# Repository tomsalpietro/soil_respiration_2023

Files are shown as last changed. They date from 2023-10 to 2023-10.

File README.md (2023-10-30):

# Soil Respiration Project
Repository of the soil respiration project

# Building
To build the image, run the following commands:
```
west build
west sign -t imgtool
```
# Flashing
To flash, run:
```
west flash
```
# OTA
To update the firmware over-the-air, run the following commands in the ./build/zephyr directory:
```
sudo python3 -m http.server 80
```

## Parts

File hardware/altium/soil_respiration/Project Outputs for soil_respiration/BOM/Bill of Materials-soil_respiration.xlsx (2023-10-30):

Description | Designator | Footprint | LibRef | Quantity | Category | Supplier 1 | Supplier Currency 1 | Supplier Order Qty 1 | Supplier Packaging 1 | Supplier Part Number 1 | Supplier Stock 1 | Supplier Subtotal 1 | Supplier Subtotal per Board 1 | Supplier Unit Price 1
CONN HEADER VERT 2POS 2.54MM | J1 | HDR2x1 | CMP-1502-00584-2 | 1 |  | Digi-Key | AUD | 1 | Bulk | 732-2695-ND | 10842 | 0.83897 | 0.83897 | 0.83897
LQ Relays, 5 V Coil Voltage, 400 mW Nominal Operating Power, -40 to 85 degC, 5-Pin LQ, Carton, Case, RoHS | K1, K2 | ALQ105 | CMP-1503-00191-1 | 2 |  | Digi-Key | AUD | 2 | Tube | 255-3565-ND | 80829 | 3.93 | 3.93 | 1.96
ON Semi TIP120G NPN Darlington Transistor 8 A 60 V HFE: 1000 3-Pin TO-220 | Q1, Q2 | TIP120G | TIP120G | 2 | BJTs | Digi-Key | AUD | 2 | Tube | TIP120GOS-ND | 0 | 2.19 | 2.19 | 1.09
Res 1K Ohm 1% 2W 1206 | R1, R2 | 1206-1k | 3503G2B1K0FTDF | 2 | Chip SMD Resistors | Digi-Key | USD |  |  | 1712-3503G2B1K0FTDFTR-ND | 0
ESP32-WROOM-32E 4MB Flash | U2 | ESP32 | ESP32-DEVKITC-32E | 1 | RF Semiconductors and Devices | Digi-Key | AUD | 1 | Bulk | 1965-ESP32-DEVKITC-32E-ND | 580 | 15.58 | 15.58 | 15.58
SCD30 Series 5.5 V 75 mA ±3% Carbon Dioxide (CO2) Sensor Module | U1 | SCD30 | SCD30 | 1 | Sensors | Digi-Key | AUD | 1 | Tray | 1649-1098-ND | 21436 | 92.57 | 92.57 | 92.57
Diode Gen Purp 50V 1A Sma | D1, D2 | S1A | S1A | 2 | Uncategorized | Digi-Key | AUD | 2 |  | 1655-S1ADKR-ND | 79124 | 0.38952 | 0.38952 | 0.19476

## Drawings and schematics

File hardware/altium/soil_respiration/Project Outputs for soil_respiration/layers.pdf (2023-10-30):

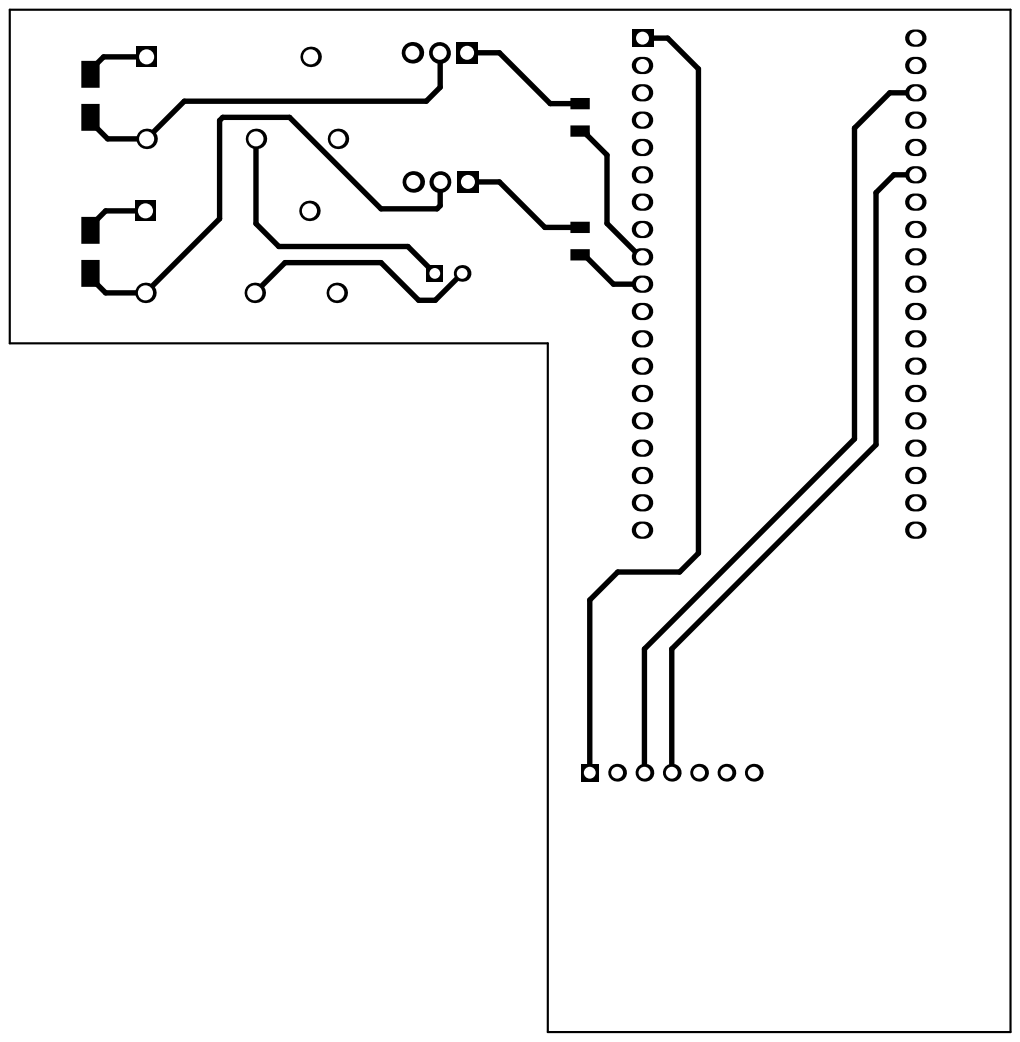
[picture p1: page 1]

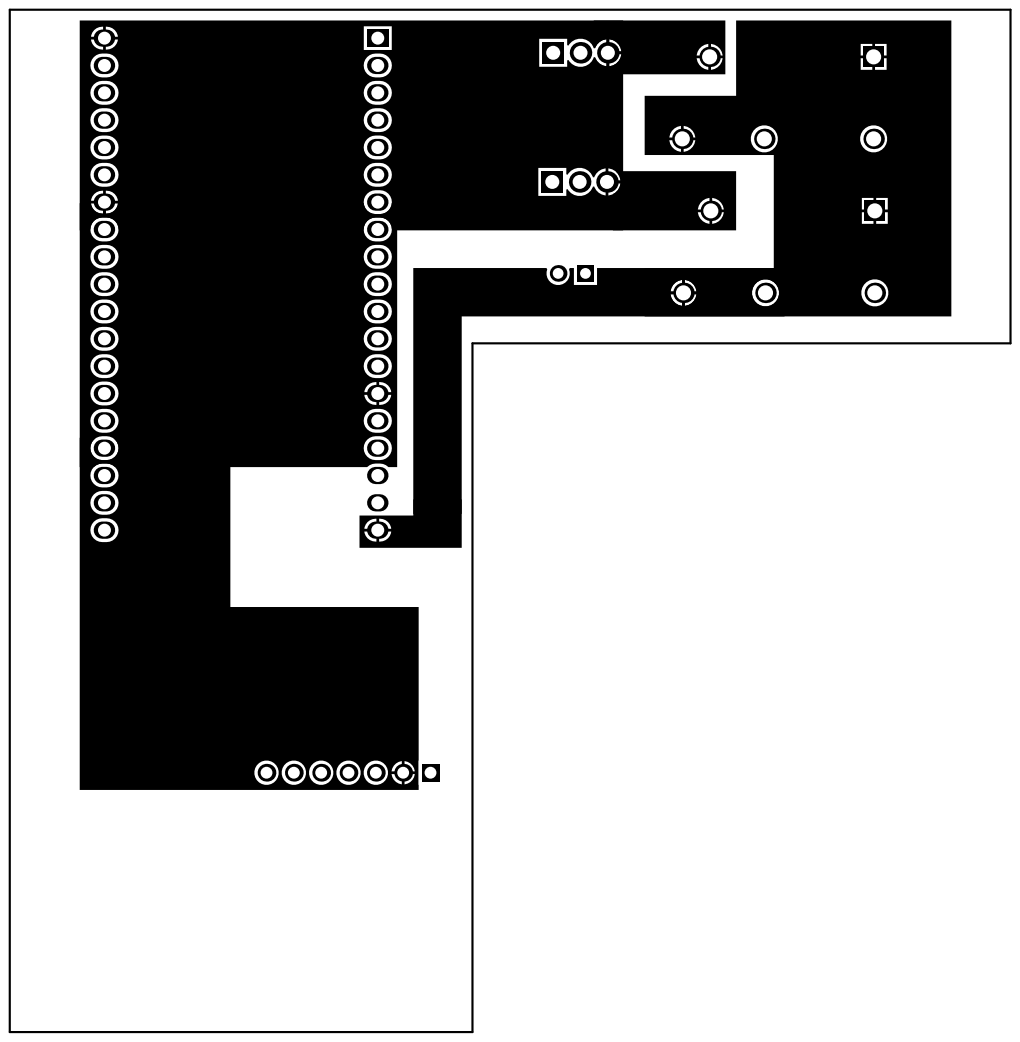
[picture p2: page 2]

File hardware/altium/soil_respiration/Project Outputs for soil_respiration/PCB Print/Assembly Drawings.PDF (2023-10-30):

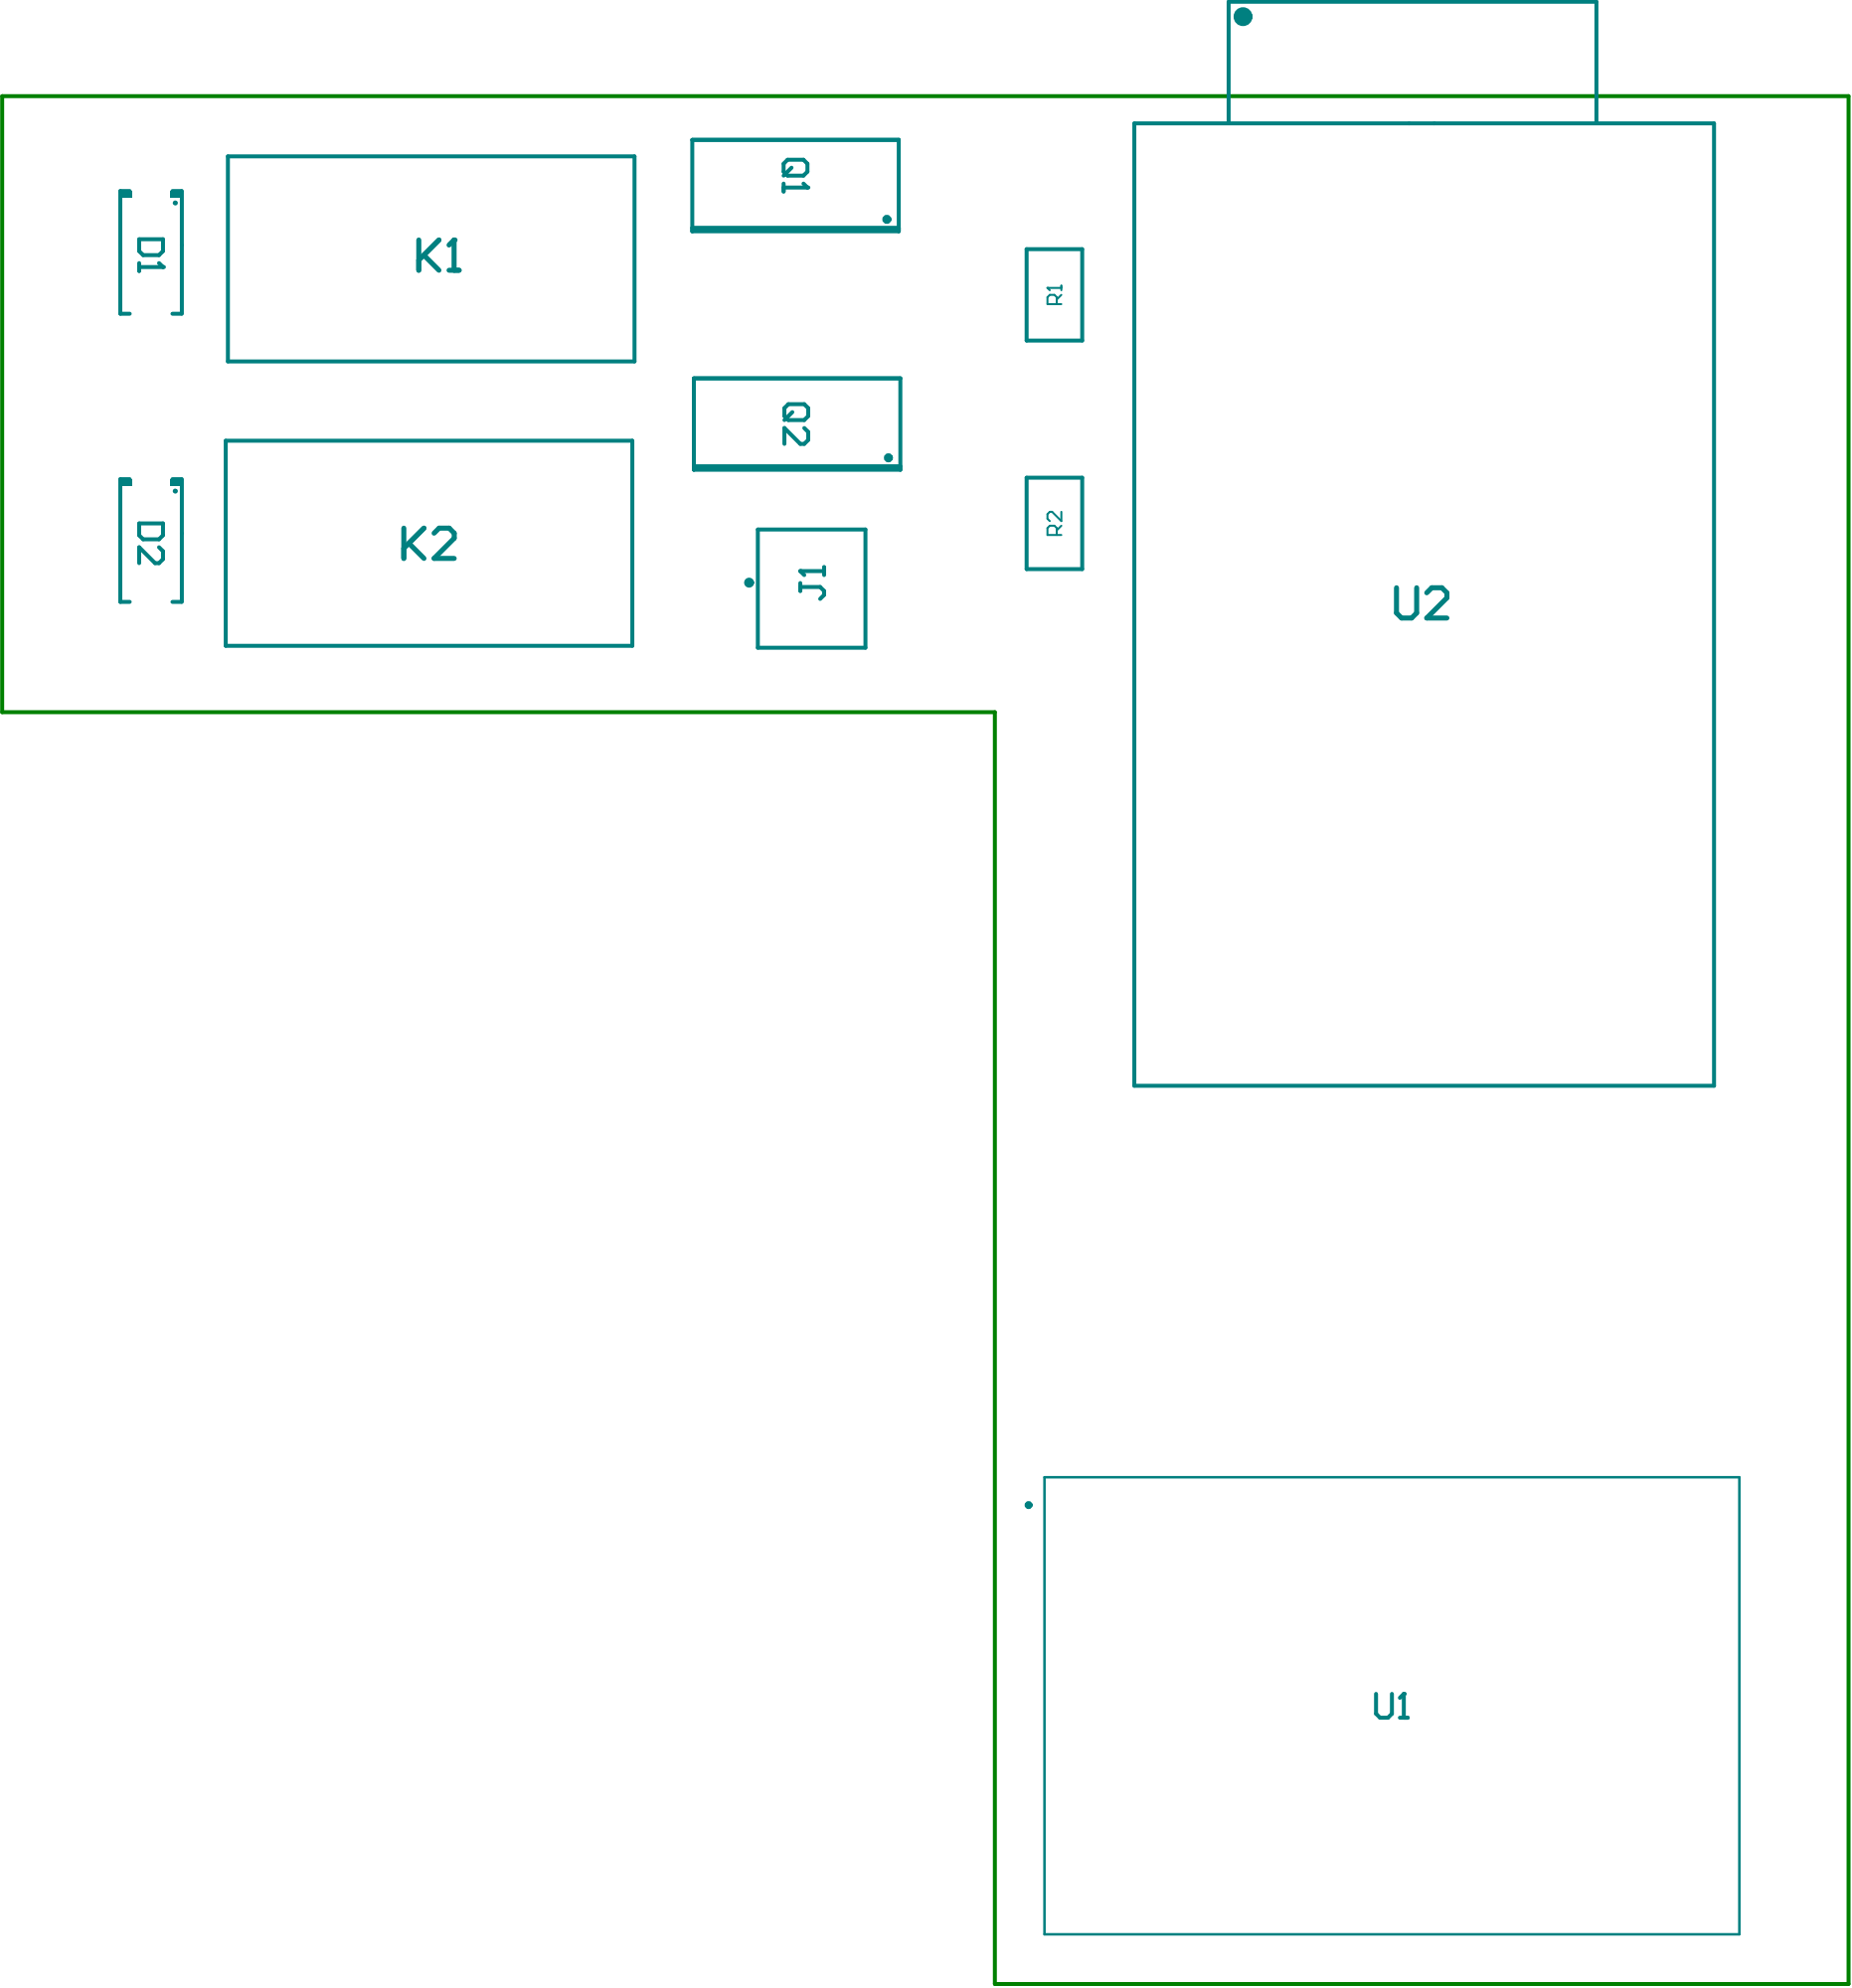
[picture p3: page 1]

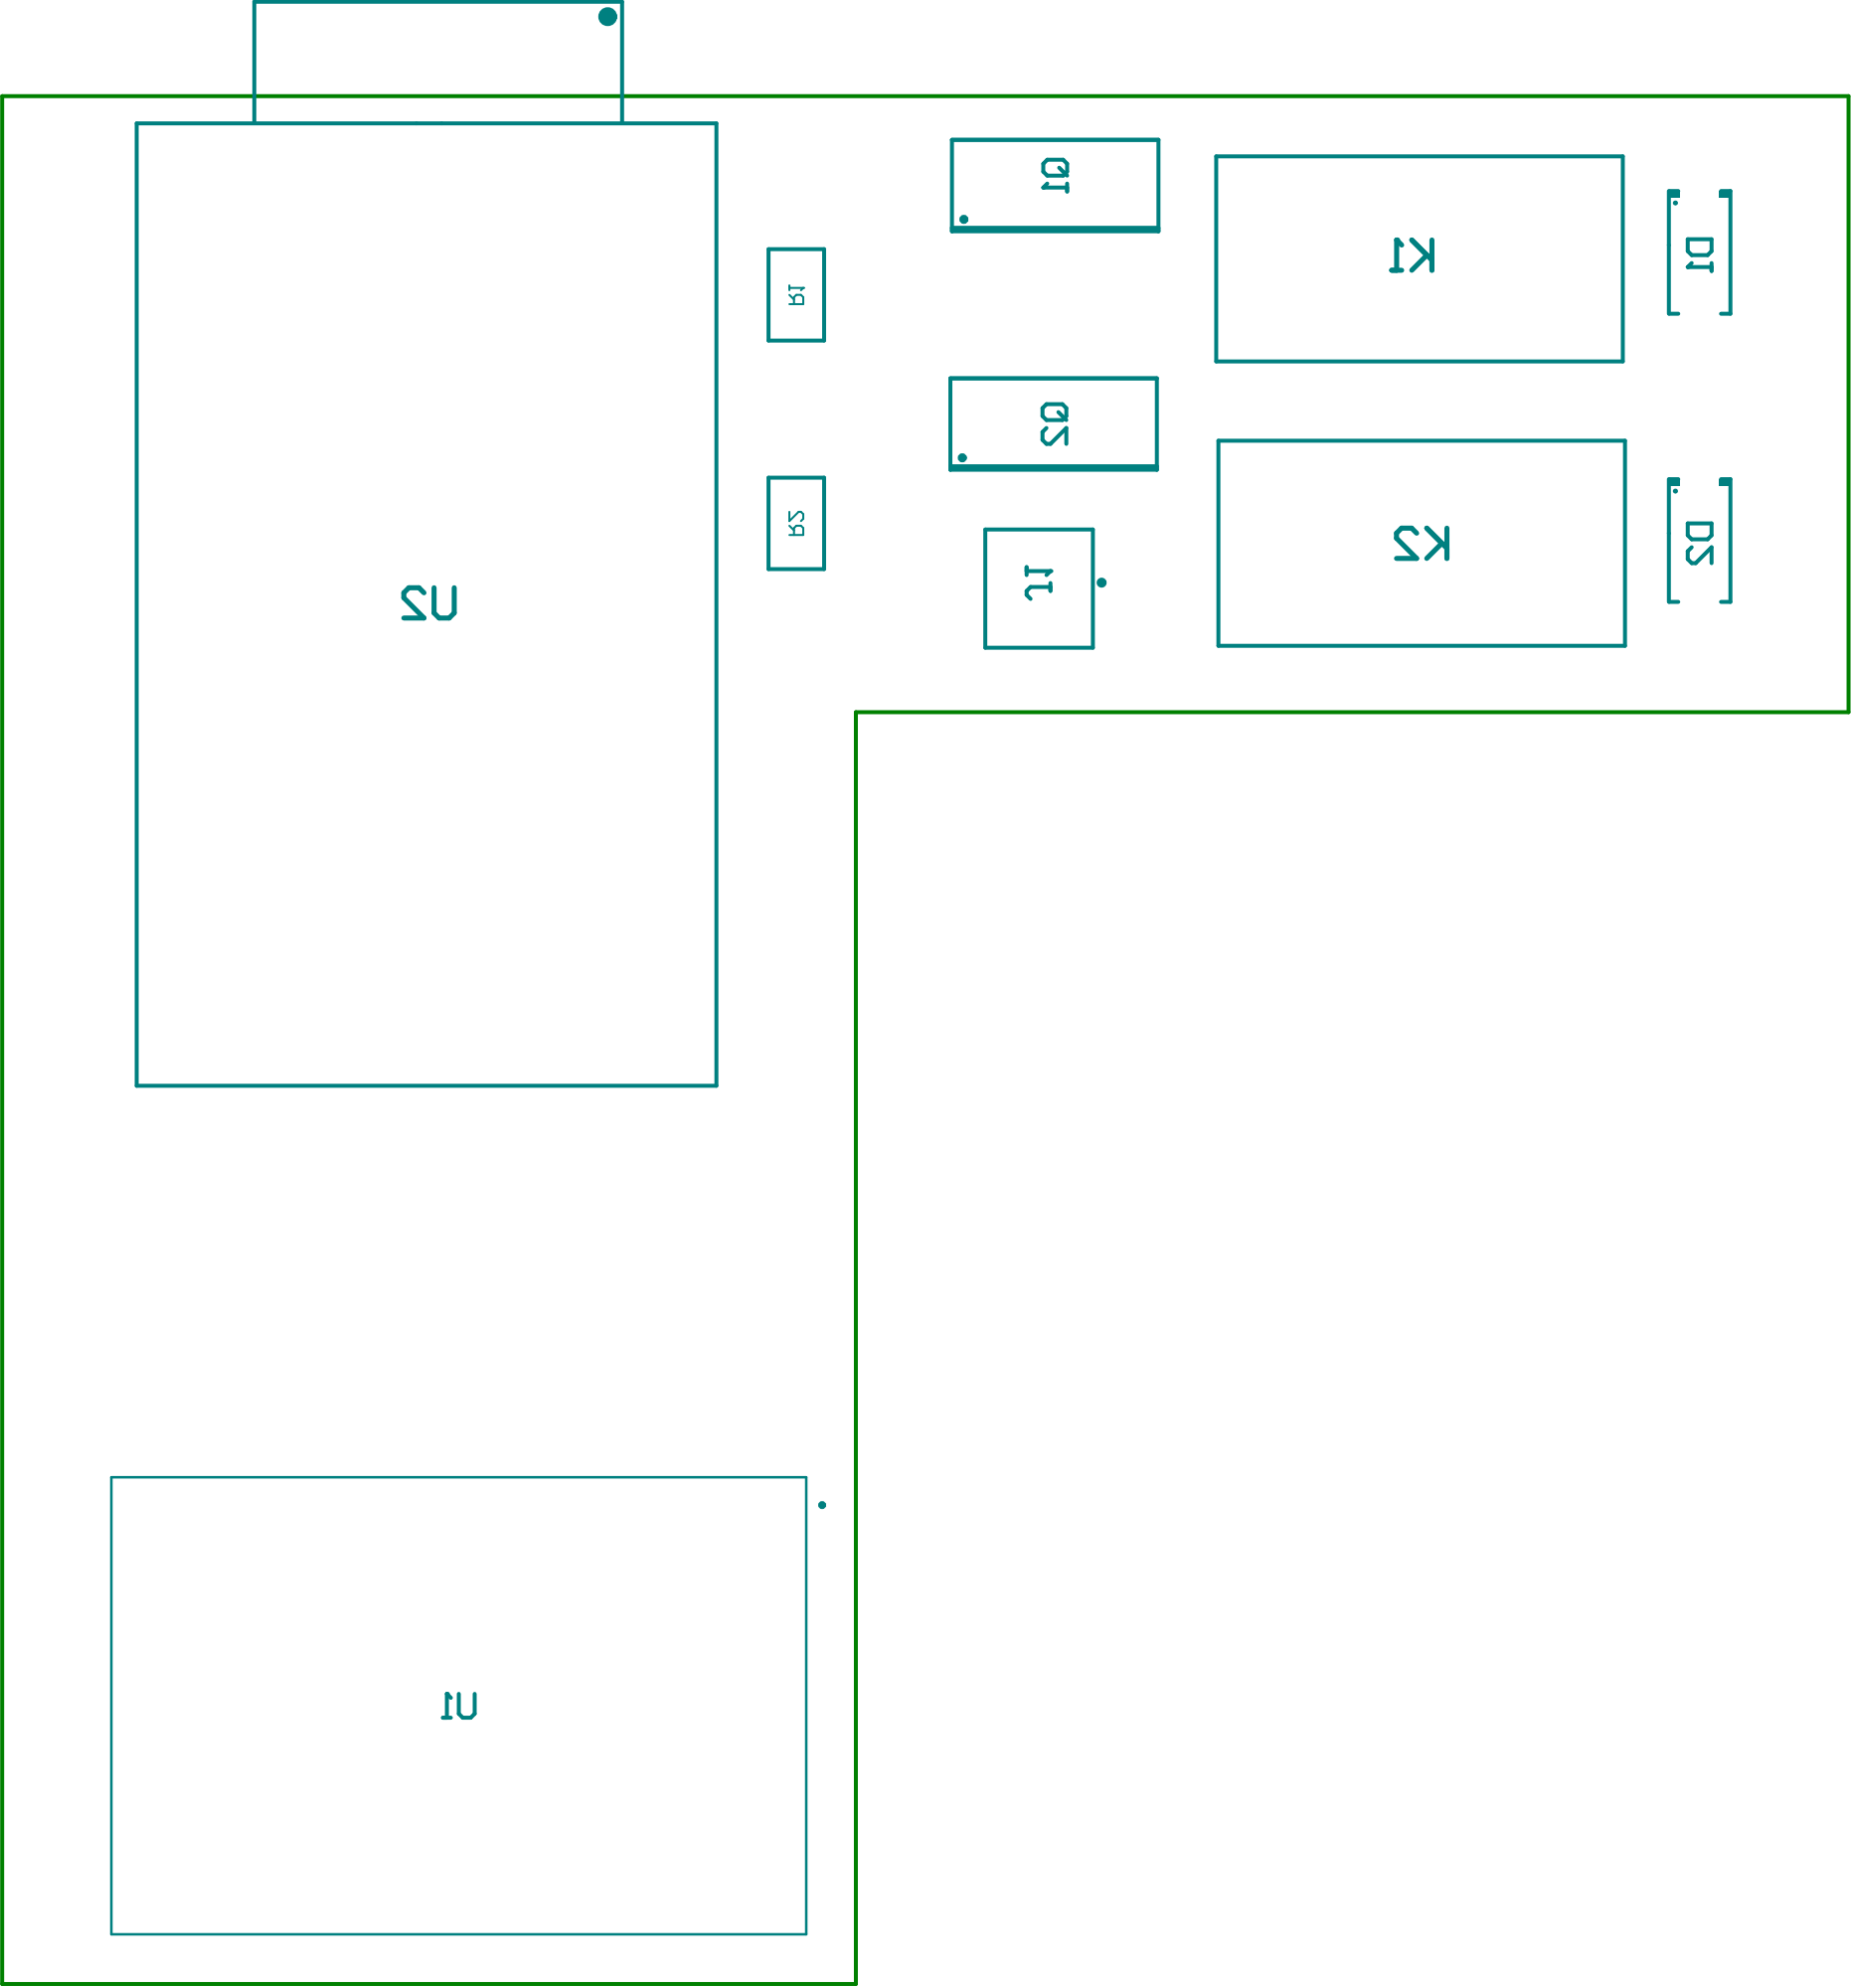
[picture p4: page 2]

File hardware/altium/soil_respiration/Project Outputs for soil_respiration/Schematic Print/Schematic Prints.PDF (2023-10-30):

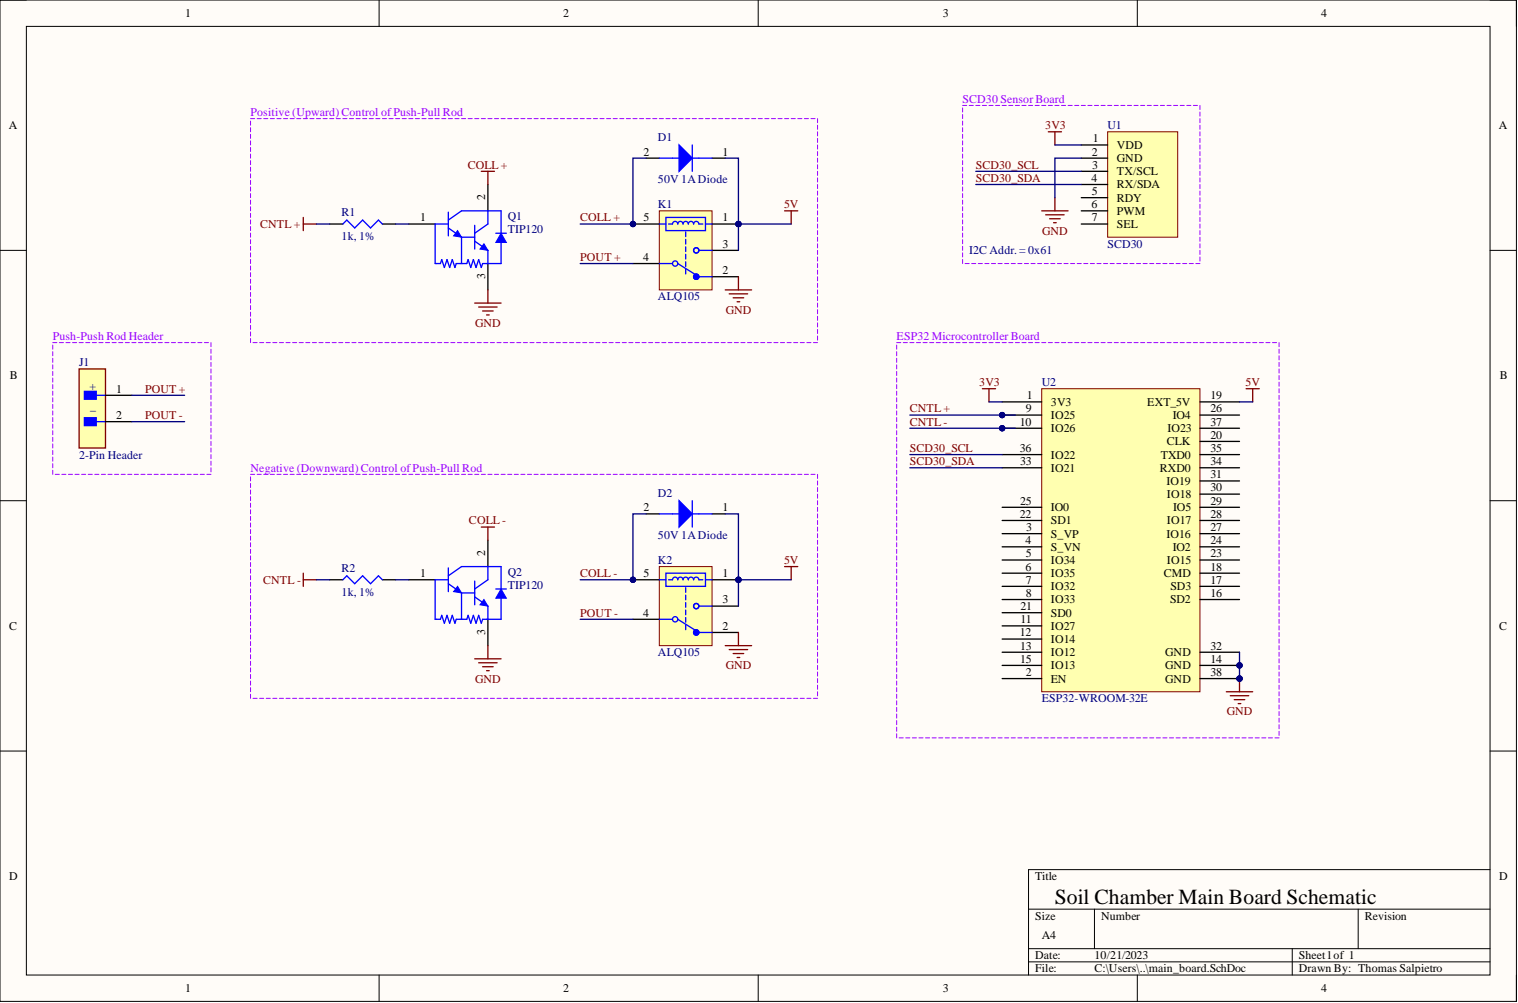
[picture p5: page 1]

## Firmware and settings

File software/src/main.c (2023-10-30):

/*
 * @file src/main
 * @author Thomas Salpietro 45822490
 * @date 02/04/2023
 * @brief main.c - starting threads
 * 
 * SPDX-License-Identifier: Apache-2.0
 */
#include <zephyr/kernel.h>
#include <zephyr/net/http/client.h>

#include <zephyr/logging/log.h>
LOG_MODULE_REGISTER(soil_respiration, LOG_LEVEL_DBG);

#include "wifi.h"
#include "mqtt.h"
#include "sockets.h"
#include "motor.h"
#include "sensor.h"
#include "ble.h"

#define WIFI_STACK_SIZE     4096
#define WIFI_PRIORITY       1

#define MQTT_STACK_SIZE     8192   
#define MQTT_PRIORITY       -3

#define HTTP_STACK_SIZE 	4096
#define HTTP_PRIORITY		-2	

#define SENSOR_STACK_SIZE 	1024
#define SENSOR_PRIORITY		1	

#define MOTOR_STACK_SIZE 	2048
#define MOTOR_PRIORITY		-1	

#define BLE_STACK_SIZE		2048
#define BLE_PRIORITY		-1


K_THREAD_DEFINE(wifi_tid, WIFI_STACK_SIZE,
	thread_wifi_entry, NULL, NULL, NULL,
	WIFI_PRIORITY, 0, 100);

K_THREAD_DEFINE(sensor_tid, SENSOR_STACK_SIZE,
	thread_sensor_entry, NULL, NULL, NULL,
	SENSOR_PRIORITY, 0, 100);


K_THREAD_DEFINE(mqtt_tid, MQTT_STACK_SIZE,
	thread_mqtt_entry, NULL, NULL, NULL,
	MQTT_PRIORITY, 0, 100);

K_THREAD_DEFINE(motor_tid, MOTOR_STACK_SIZE,
	thread_entry_motor, NULL, NULL, NULL,
	MOTOR_PRIORITY, 0, 100);

K_THREAD_DEFINE(ble_tid, BLE_STACK_SIZE,
	ble_thread_entry, NULL, NULL, NULL,
	BLE_PRIORITY, 0, 100);

int main(void) {

    k_thread_start(wifi_tid);
    k_thread_start(mqtt_tid);
	k_thread_start(sensor_tid);
	k_thread_start(motor_tid);

	k_thread_start(ble_tid);

    return 0;
}

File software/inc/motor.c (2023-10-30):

/**
 ************************************************************************
 * @file inc/motor.c
 * @author Thomas Salpietro 45822490
 * @date 06/04/2023
 * @brief Contains source code for the motor driver
 **********************************************************************
 * */

#include <zephyr/kernel.h>
#include <zephyr/device.h>
#include <zephyr/drivers/gpio.h>
#include <zephyr/sys/util.h>
#include <zephyr/logging/log.h>
#include "motor.h"
#include "wifi.h"

LOG_MODULE_REGISTER(soil_respiration_chamber);

//IO 25 and 26
#define SW1_NODE DT_ALIAS(sw1)
#define SW2_NODE DT_ALIAS(sw2)
#define TICKS_PER_SEC               10000
#define FIVE_SEC_TIMEOUT_MS         5000
#define ONE_MIN_TIMEOUT_MS          60000
#define ONE_HOUR_TIMEOUT_MS         3600000
#define FIFTEEN_MIN_TIMEOUT_MS      900000
#define FORTY_FIVE_MIN_TIMEOUT_MS   2700000
#define FIVE_MIN_TIMEOUT_MS         300000
#define SIX_SEC_TIMEOUT_MS          6000

static const struct gpio_dt_spec motorUp = GPIO_DT_SPEC_GET_OR(SW1_NODE, gpios, {0});
static const struct gpio_dt_spec motorDown = GPIO_DT_SPEC_GET_OR(SW2_NODE, gpios, {0});

States state = INIT;
int64_t period = (int64_t)FIFTEEN_MIN_TIMEOUT_MS;


void thread_entry_motor(void) {
    int ret;
    	
    ret = gpio_pin_configure_dt(&motorUp, GPIO_OUTPUT_INACTIVE);
    if (ret != 0) {
		printk("Error %d: failed to configure UP device %s pin %d\n",
		    ret, motorUp.port->name, motorUp.pin);
		//motorUp.port = NULL;
	} else {
		printk("Set up UP at %s pin %d\n", motorUp.port->name, motorUp.pin);
	}


    ret = gpio_pin_configure_dt(&motorDown, GPIO_OUTPUT_INACTIVE);
    if (ret != 0) {
		printk("Error %d: failed to configure DOWN device %s pin %d\n",
		    ret, motorDown.port->name, motorDown.pin);
		//motorDown.port = NULL;
	} else {
		printk("Set up DOWN at %s pin %d\n", motorDown.port->name, motorDown.pin);
	}

    
    int64_t upTime = 0;

    if (!gpio_is_ready_dt(&motorUp)) {
        printk("Up not ready\r\n");
		return 0;
	}
    if (!gpio_is_ready_dt(&motorDown)) {
        printk("down not ready\r\n");
		return 0;
	}

    

    while (true) {
        while (!wifiConnected) {
            //do nothing
            k_msleep(100);
            
        }
        

        switch(state) { 
            case INIT: 
                //init state
                //turn all the way up, then turn all the way down.
                LOG_INF("Initialising Chamber...\r\n");
                gpio_pin_set_dt(&motorUp, 1);
                k_msleep(200);
                gpio_pin_set_dt(&motorDown, 0);
                //printk("Going up\r\n");
                k_msleep(6000);
                gpio_pin_set_dt(&motorUp, 0);
                k_msleep(200);
                gpio_pin_set_dt(&motorDown, 0);
                k_msleep(1000);
                //printk("going down\r\n");
                gpio_pin_set_dt(&motorDown, 1);
                k_msleep(200);
                gpio_pin_set_dt(&motorUp, 0);
                k_msleep(6000);
                gpio_pin_set_dt(&motorDown, 0);
                
                state = SENSING_BEGIN;
                gpio_pin_set_dt(&motorDown, 1);
                gpio_pin_set_dt(&motorUp, 0);
                upTime = k_uptime_get();
                break;
            case SENSING_BEGIN:
                //turn off (DOWN) all the w
                // so if it is already set, we want to check if the uptime has ticked over 5 seconds, then switch off gpio and change state
                if (k_uptime_get() - upTime > (int64_t)SIX_SEC_TIMEOUT_MS) {
                    // so its gone on longer than 5 seconds - turn it off and change state
                    gpio_pin_set_dt(&motorDown, 0);
                    k_msleep(500);
                    gpio_pin_set_dt(&motorUp, 0);
                    upTime = k_uptime_get();
                    state = SENSING;
                    LOG_INF("Begin Sensing... \r\n");
                }
                else {
                    k_msleep(1000);
                }
                
                break;
            case SENSING:
                // this should keep track of time (1 minute), after a minute has passed, change state to SENSING_END
                if (k_uptime_get() - upTime > period) {
                    //1 minute elapsed, change state to sensing end
                    LOG_INF("Done Sensing!");
                    gpio_pin_set_dt(&motorUp, 1);
                    gpio_pin_set_dt(&motorDown, 0);
                    upTime = k_uptime_get();
                    state = SENSING_END;
                } else {
                    //15 minutes still going - do nothing
                    k_msleep(1000);
                }
                break;  
            case SENSING_END:                   
                // so if it is already set, we want to check if the uptime has ticked over 5 seconds, then switch off gpio and change state
                if (k_uptime_get() - upTime > (int64_t)SIX_SEC_TIMEOUT_MS) {
                    // so its gone on longer than 5 seconds - turn it off and change state
                    gpio_pin_set_dt(&motorUp, 0);
                    k_msleep(500);
                    gpio_pin_set_dt(&motorDown, 0);
                    upTime = k_uptime_get();
                    state = SLEEP;
                } else {
                    k_msleep(1000);
                }
                

                break;
            case SLEEP:
                k_msleep(5000);
                // do nothing state - check to see if 1 hour has passed
                if ((k_uptime_get() - upTime) > ((int64_t)ONE_HOUR_TIMEOUT_MS - period - (int64_t)SIX_SEC_TIMEOUT_MS - (int64_t)SIX_SEC_TIMEOUT_MS)) {
                    //one hour has passed - change state
                    state = SENSING_BEGIN;
                    gpio_pin_set_dt(&motorDown, 1);
                    gpio_pin_set_dt(&motorUp, 0);
                    upTime = k_uptime_get();
                } else if ((k_uptime_get() - upTime) % 60000){
                    LOG_INF("Sleep time remaining: %lld minutes", ((int64_t)ONE_HOUR_TIMEOUT_MS - period - (k_uptime_get() - upTime)) / 60000);
                }
                break; 
        }
        k_msleep(100);


    }


}

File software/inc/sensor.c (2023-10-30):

/**
 ************************************************************************
 * @file inc/sensor.c
 * @author Thomas Salpietro 45822490
 * @date 02/04/2023
 * @brief Contains source code for the sensor driver
 **********************************************************************
 * */


#include <zephyr/kernel.h>
#include <zephyr/device.h>
#include <stdio.h>
#include <zephyr/logging/log.h>

#include "scd30.h"
#include "sensirion_common.h"
#include "sensor.h"
#include "motor.h"

LOG_MODULE_REGISTER(soil_respiration_sensor);

#define SCD30_ALIAS     DT_ALIAS(i2c_0)

float sensorData[3];
bool sensorTransmit = false;


void thread_sensor_entry(void) {

    // variables
    float co2, temperature, relativeHumidity;
    int16_t err;
    uint16_t dataReady, ver;
    uint16_t intervalSeconds = 5;
    uint16_t timeout = 0;


    //i2c dev
    const struct device *i2cDev = DEVICE_DT_GET(SCD30_ALIAS);

    if (!device_is_ready(i2cDev)) {
		printk("I2C: Device is not ready.\r\n");
		return;
	}


    scd30_get_driver_version(&ver, i2cDev);
    printk("Device ready. Firmware Version: %d\r\n", ver);

    //k_msleep(25000);
    // set measurment interval - 2 seconds
    scd30_set_measurement_interval(intervalSeconds, i2cDev);
    // start measurements
    scd30_start_periodic_measurement(0, i2cDev);

    while(1) {
        if (state == SENSING){
            scd30_get_data_ready(&dataReady, i2cDev);

            
            if (dataReady) {
                //get co2
                err = scd30_read_measurement(&sensorData[0], &sensorData[1], &sensorData[2], i2cDev);
                if (err != NO_ERROR) {
                    LOG_ERR("error reading measurement\r\n");
                } else {
                    LOG_INF("measured co2 concentration: %0.2f ppm, "
                    "measured temperature: %0.2f degreeCelsius, "
                    "measured humidity: %0.2f %%RH\r\n",
                    sensorData[0], sensorData[1], sensorData[2]);
                    sensorTransmit = true;
                }
            }
        } else {
            k_msleep(5000);
        }
        /*
        else if (state == SENSING_END) {
            scd30_stop_periodic_measurement(i2cDev);
            k_msleep(4000);
        } else if (state == SENSING_BEGIN) {
            scd30_start_periodic_measurement(0, i2cDev);
            k_msleep(4000);
        }*/
        

        

    }



    
}

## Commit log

2023-05-10 Sensor libraries, socket functionality, wifi updates, thread changes
2023-06-23 Initial altium commit
    [main_board.PcbDoc, main_board.SchDoc, main_board_PcbLib1.PcbLib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]
2023-10-30 Hardware files committed - final PCB
    [Bill of Materials-soil_respiration.xlsx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]
